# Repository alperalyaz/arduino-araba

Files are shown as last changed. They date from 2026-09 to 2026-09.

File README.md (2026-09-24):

# Faruk'un Arduino Arabası

Yıllar önce bir robotik kodlama setiyle yapılmış "çarpmayan araba" projesinin
yeniden canlandırılması. Orijinal kod kayıp (karttan geri alınamıyor), her şey sıfırdan yazılıyor.

## Donanım

| Parça | Model | Durum |
|---|---|---|
| Kart | Arduino Uno R3 klonu (EDUBOTICS), CH340 USB | ✅ Çalışıyor |
| Motor sürücü | L298N, **HW-095** | ✅ Hazır, jumper'ları ayarlandı |
| Mesafe sensörü | HC-SR04 (çok modlu klon, fabrika modu standart) | ✅ Çalışıyor, test edildi |
| Motorlar | 2× sarı TT redüktörlü, tekerlekli | ⏳ Test edilmedi |
| Çizgi sensörü | 2× HW-870 (TCRT5000), 4 pinli | ⏳ Bağlanmadı |
| Pil | 2× 18650, yeni, tam şarjlı | ✅ Hazır |
| Gövde | Lazer kesim ahşap, marka NCT, ön bilyeli teker | — |

**Port:** COM3 &nbsp;•&nbsp; **FQBN:** `arduino:avr:uno` &nbsp;•&nbsp; "old bootloader" gerekmiyor

## Dosyalar

| Dosya | Ne işe yarar |
|---|---|
| [KABLO-HARITASI.md](KABLO-HARITASI.md) | **Ana referans.** Hangi kablo nereye. |
| [KAYRA.md](KAYRA.md) | Uygulayacak kişi için adım adım talimat |
| `BlinkTest/` | Kart canlı mı — en temel test |
| `MesafeTest/` | HC-SR04 ölçüm testi (pil gerekmez) |
| `MotorTest/` | Motorları tek tek döndürür (pil gerekir) |
| `CizgiTest/` | HW-870 testi (henüz kullanılmadı) |
| `ardiuno-claude.cmd` | Masaüstü kısayolunun çalıştırdığı dosya |

## Komutlar

Derle ve yükle:

```bash
"C:\Program Files\Arduino CLI\arduino-cli.exe" compile --fqbn arduino:avr:uno --upload -p COM3 C:\ardiuno\MesafeTest
```

Kart bağlı mı:

```bash
"C:\Program Files\Arduino CLI\arduino-cli.exe" board list
```

**Seri port okuma:** `arduino-cli monitor` kullanma — interaktif, oturumu kilitler.
Bunun yerine PowerShell `System.IO.Ports.SerialPort` + `ReadExisting()` döngüsü kullan,
`finally` içinde mutlaka `Close()`/`Dispose()`.

## Bilinen tuzaklar

- **L298N'in ENA/ENB jumper kapakları** çıkarılmış olmalı. Takılıyken Arduino pini bağlanırsa pin yanar.
- **"5V" jumper'ı takılı kalmalı.** Çıkarılırsa motorlar hiç dönmez.
- **Arduino 5V pini ile L298N +5V klemensi asla birleştirilmez.** (Arduino VIN'e pil gerilimi vermek serbest.)
- **Servo kullanılırsa** Timer1'i alır, D9 ve D10'un hız ayarı ölür. ENA/ENB bu yüzden D11 ve D6'da.
- **D0 ve D1 kullanılmaz** — seri port oradan konuşuyor.
- **Blink testinde 1 saniyelik desen kullanma** — fabrika çıkışı deseniyle aynı, sahte başarı üretir.
- Arduino'da **1 adet 5V, 3 adet GND** deliği var. Üç sensör birden bağlanacaksa
  **breadboard veya sensör shield** gerekli.

## Sıradaki

1. Motor testi (kablolama + pil) — `MotorTest/`
2. Çarpmayan araba (mesafe + motor birlikte)
3. Çizgi takibi (shield/breadboard geldikten sonra)

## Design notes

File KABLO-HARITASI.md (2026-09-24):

# FARUK'UN ARABASI - KABLO HARITASI  (v2, duzeltilmis)
23 Eylul 2026

## !!! KABLO TAKMADAN ONCE YAPILACAKLAR !!!

1. [TAMAM - 23 Eylul 2026] ENA/ENB jumper kapaklari CIKARILDI.
   Kart modeli: HW-095 (standart kirmizi L298N).
   Kapaklarin altindan cikan 2'ser pimden:
     - +5V klemensiyle SUREKLILIK VEREN (oten) pim  = +5V   -> kablo TAKMA
     - SUREKLILIK VERMEYEN (otmeyen) pim            = ENA / ENB -> KABLO BURAYA
   Kullanicinin elindeki duruma gore: OTMEYEN = ALTTAKI pim.
   Kablo takarken bu olcum 10 saniyede TEKRARLANACAK (kart cevrilirse ust/alt degisir).
2. "5V" jumper'i (kartin orta-sol kisminda, 102 yazan parcanin yaninda)
   YERINDE KALACAK. Cikarilirsa motorlar hic donmez.
3. Sokmeden once FOTOGRAF cek ve her kabloyu BANTLA ETIKETLE.
4. Her takma/sokme isleminde: kirmizi anahtar KAPALI + USB CIKIK.

## ARDUINO PIN HARITASI

### Motor surucu (L298N) - 6 kablo, ARDISIK
| L298N ustundeki yazi | Arduino deligi | Ne ise yarar |
|---|---|---|
| ENA | 11 | Sol motor HIZ |
| IN1 | 10 | Sol motor YON |
| IN2 | 9 | Sol motor YON |
| IN3 | 8 | Sag motor YON |
| IN4 | 7 | Sag motor YON |
| ENB | 6 | Sag motor HIZ |

11-10-9-8-7-6 sirayla iniyor. Serit kablo duz gider.

NEDEN 10 ve 9 DEGIL de 11 ve 6?  Servo motor kullanilirsa Arduino'nun
ic sayaci 9 ve 10'un hiz ayarini KAPATIYOR. O zaman motorlar yavas
gitmek yerine TAM GAZ kalkar. 11 ve 6 bundan etkilenmiyor.

### Mesafe sensoru (HC-SR04) - 4 kablo
| Sensor ustundeki yazi | Arduino deligi |
|---|---|
| VCC | 5V |
| Trig | 4 |
| Echo | 2 |
| GND | GND |

### Cizgi sensorleri (HW-870) - EN SON ASAMA
| Sensor | VCC | GND | DO  |
|---|-----|-----|-----|
| Sol | 5V  | GND | A0  |
| Sag | 5V  | GND | A1  |

## GUC BAGLANTISI

### Test asamasinda (tekerlekler havada)
- Arduino: USB'den beslenir
- Pil (+) -> SIGORTA (2-3 A) -> L298N "+12V" klemensi
- Pil (-) -> L298N "GND" klemensi
- L298N "GND" -> Arduino "GND"      <-- ILK BAGLANAN, SON SOKULEN
- L298N "+5V" -> HICBIR SEY

### Araba yerde giderken (USB cikik)
- Pil (+) -> SIGORTA -> hem L298N "+12V" hem Arduino "VIN"
- Pil (-) -> L298N "GND" ve Arduino "GND"

## MUTLAK KURALLAR
- Arduino "5V" pini ile L298N "+5V" klemensi ASLA BIRLESTIRILMEZ.
  (Arduino "VIN" pinine pil gerilimi vermek ise SERBEST ve dogru.)
- Pil (+) hattinda SIGORTA olmadan pil takilmaz.
- Motor hizi kodda en fazla 200 (255 degil). Ilk testler 120-150.
- Kirmizi = arti, Siyah = eksi. Istisnasiz.

## MOTORLAR
- Sol motorun 2 kablosu  -> OUT1 / OUT2
- Sag motorun 2 kablosu  -> OUT3 / OUT4
- Kutup yonu onemsiz; ters donerse duzeltiriz

## PIN YETMEZLIGI - EK MALZEME GEREKLI
Arduino'da 1 tane 5V deligi, 3 tane GND deligi var.
Ihtiyac: 5V'a 3 cihaz, GND'ye 4 cihaz. SIGMIYOR.
=> Breadboard (deneme tahtasi) veya vidali dagitim klemensi gerekli.

## BOSTA KALAN PINLER
D3, D5, D12, D13(dahili LED), A2, A3, A4, A5
D0 ve D1 KULLANILMAZ - seri port oradan konusuyor
Servo gerekirse -> D3 veya D12

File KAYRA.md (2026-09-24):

# KAYRA — YAPILACAKLAR

## 0. Değişmez kurallar

- Kablo takarken/sökerken: **USB çıkık, pil bağlı değil.**
- Test sırasında araba **kitabın üstünde**, tekerlekler havada.
- Kırmızı = artı. Siyah = eksi.
- Duman, koku veya ısınma → pili çıkar, USB'yi çek.

## 1. Kabloları bağla

Önce ortak şase:

```
L298N "GND" klemensi  →  Arduino GND
```

Sonra altı komut kablosu:

| L298N | Arduino |
|---|---|
| ENA | 11 |
| IN1 | 10 |
| IN2 | 9  |
| IN3 | 8  |
| IN4 | 7  |
| ENB | 6  |

ENA ve ENB'de iki pim var. Multimetreyi süreklilik kademesine al.
Bir probu L298N "+5V" klemensine koy. Ötmeyen pime kabloyu tak.

Sonra motorlar:

```
Sol motor  →  OUT1 / OUT2
Sağ motor  →  OUT3 / OUT4
```

Mesafe sensörü zaten bağlı. Dokunma. (Trig→4, Echo→2, Vcc→5V, Gnd→GND)

## 2. Pili henüz bağlama

## 3. USB'yi tak, kodu yükle

```bash
"C:\Program Files\Arduino CLI\arduino-cli.exe" compile --fqbn arduino:avr:uno --upload -p COM3 C:\ardiuno\MotorTest
```

## 4. Ekranı oku

Motorlar dönmeyecek (pil yok). Ekranda şu akmalı:

```
-> SOL motor - ILERI
-> SOL motor - GERI
-> SAG motor - ILERI
-> SAG motor - GERI
-> IKISI BIRDEN - ILERI
```

Akmıyorsa dur. Kabloyu kontrol et.

## 5. Pili bağla

```
Pil (+)  →  L298N "+12V"
Pil (-)  →  L298N "GND"
```

L298N "+5V" klemensine hiçbir şey bağlama.

## 6. İzle

- Ekranda "SOL" yazarken sol teker dönüyor mu?
- "ILERI" yazarken ileri yönde mi dönüyor?
- Ters dönen varsa **kabloyu değiştirme**, not al. Kodda düzeltilecek.

## 7. Raporla

Şunları yaz:
- Hangi motor, hangi komutta, hangi yöne döndü
- Dönmeyen motor var mı
- Isınan parça var mı

## Sorun çıkarsa

| Belirti | Bak |
|---|---|
| Hiçbir motor dönmüyor | L298N "5V" jumper'ı takılı mı |
| Ekranda yazı yok | USB kablosu, COM3 |
| Tek motor dönmüyor | O motorun OUT klemens vidaları sıkı mı |
| Hız ayarı çalışmıyor, hep tam gaz | ENA/ENB kapakları çıkmış mı |

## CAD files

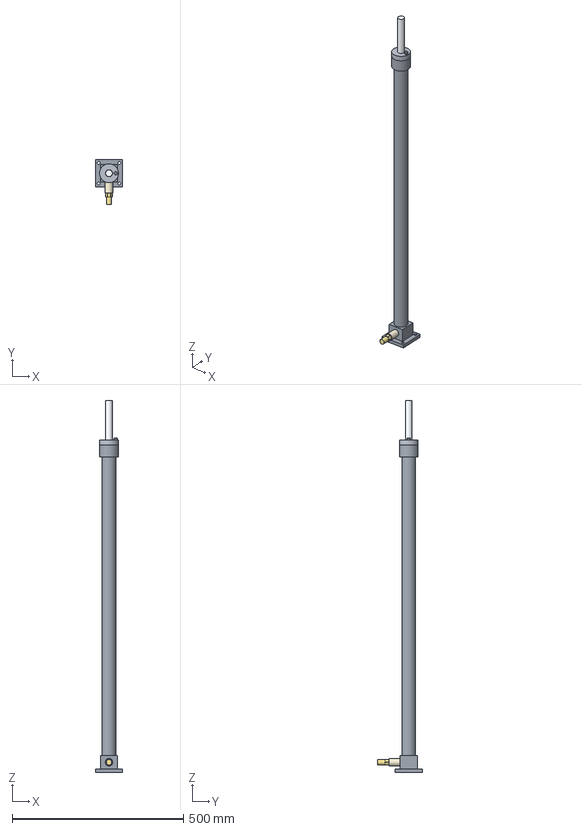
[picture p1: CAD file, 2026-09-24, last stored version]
maket-cad/hidrolik/silindir.step
80.0 x 131.0 x 1085.0 mm
SILINDIR_AYAK_PLAKASI
SILINDIR_DIP_BLOGU
SILINDIR_GOMLEK
SILINDIR_KAFA_GOVDESI
SILINDIR_KAFA_KAPAGI
SILINDIR_HAVA_ALMA_VIDASI
PISTON_MILI
STROK_SONU_HALKASI
HORTUM_PATLAMA_VALFI
HORTUM_RAKORU_SILINDIR

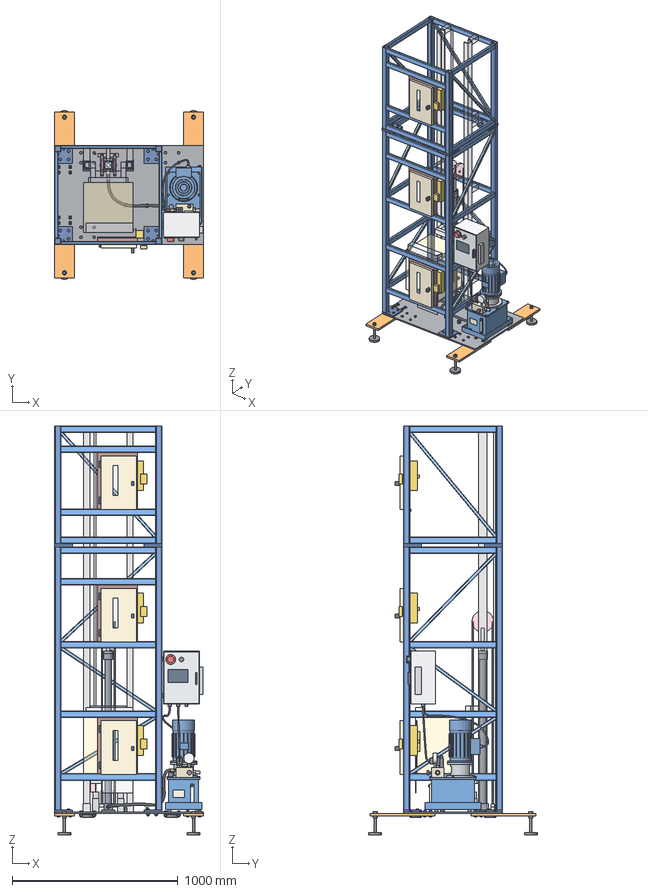
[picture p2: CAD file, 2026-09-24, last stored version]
maket-cad/taban-dikme/maket_taban_dikme.step
900.0 x 1019.4 x 2470.0 mm
TABAN_SACI
KOSE_PLAKASI_AYAK_SOL_ON
KOSE_PLAKASI_EK_ALT_SOL_ON
KOSE_PLAKASI_EK_UST_SOL_ON
DIKME_ALT_SOL_ON
DIKME_UST_SOL_ON
KOSE_PLAKASI_AYAK_SOL_ARKA
KOSE_PLAKASI_EK_ALT_SOL_ARKA
KOSE_PLAKASI_EK_UST_SOL_ARKA
DIKME_ALT_SOL_ARKA
DIKME_UST_SOL_ARKA
KOSE_PLAKASI_AYAK_SAG_ON
KOSE_PLAKASI_EK_ALT_SAG_ON
KOSE_PLAKASI_EK_UST_SAG_ON
DIKME_ALT_SAG_ON
DIKME_UST_SAG_ON
KOSE_PLAKASI_AYAK_SAG_ARKA
KOSE_PLAKASI_EK_ALT_SAG_ARKA
KOSE_PLAKASI_EK_UST_SAG_ARKA
DIKME_ALT_SAG_ARKA
DIKME_UST_SAG_ARKA
DESTEK_KULAGI_SOL_ON
DESTEK_KULAGI_SOL_ARKA
DESTEK_KULAGI_SAG_ON
DESTEK_KULAGI_SAG_ARKA
KUSAK_ALT_ON_R1
KUSAK_ALT_ON_R2
KUSAK_ALT_ON_R3
KUSAK_ALT_ON_R4
KUSAK_ALT_ON_R5
KUSAK_UST_ON_R6
KUSAK_UST_ON_R7
KUSAK_UST_ON_R8
KUSAK_UST_ON_R9
KUSAK_ALT_SOL_R1
KUSAK_ALT_SOL_R2
KUSAK_ALT_SOL_R3
KUSAK_ALT_SOL_R5
KUSAK_UST_SOL_R6
KUSAK_UST_SOL_R9
KUSAK_ALT_SAG_R1
KUSAK_ALT_SAG_R2
KUSAK_ALT_SAG_R3
KUSAK_ALT_SAG_R5
KUSAK_UST_SAG_R6
KUSAK_UST_SAG_R9
KUSAK_ALT_ARKA_R1
KUSAK_ALT_ARKA_R2
KUSAK_ALT_ARKA_R3
KUSAK_ALT_ARKA_R5
KUSAK_UST_ARKA_R6
KUSAK_UST_ARKA_R9
CAPRAZ_ALT_SOL_R1_R2
CAPRAZ_ALT_SOL_R2_R3
CAPRAZ_ALT_SOL_R3_R5
CAPRAZ_UST_SOL_R6_R9
CAPRAZ_ALT_SAG_R1_R2
CAPRAZ_ALT_SAG_R2_R3
CAPRAZ_ALT_SAG_R3_R5
CAPRAZ_UST_SAG_R6_R9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

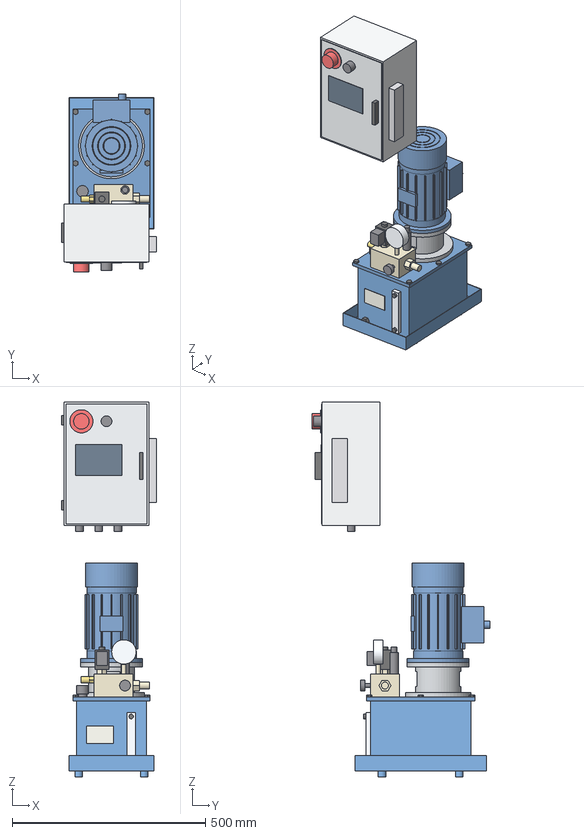
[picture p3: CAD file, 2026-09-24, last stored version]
maket-cad/hidrolik/unite.step
247.0 x 460.0 x 970.0 mm
YAG_TAVASI
TAVA_AYAGI_-85_-100
TAVA_AYAGI_-85_100
TAVA_AYAGI_85_-100
TAVA_AYAGI_85_100
TANK
TANK_KAPAGI
KAPAK_CIVATASI_-93_-133
KAPAK_CIVATASI_93_-133
KAPAK_CIVATASI_-93_133
KAPAK_CIVATASI_93_133
KAPAK_CIVATASI_-93_0
KAPAK_CIVATASI_93_0
CAN_KAMPANA
MOTOR_IEC71_B5_0_25kW
VALF_BLOGU
INIS_VALFI_KARTUSU
INIS_VALFI_BOBINI
INIS_VALFI_SOMUNU
INIS_VALFI_FISI_DIN
EMNIYET_VALFI
ELLE_INDIRME
MANOMETRE_BOGAZI
MANOMETRE
BASINC_SENSORU
HORTUM_RAKORU_BLOK
HAVA_DOLUM_TAPASI
SEVIYE_GOSTERGESI
SEVIYE_CIVATASI_46
SEVIYE_CIVATASI_156
BOSALTMA_TAPASI
UNITE_ETIKETI
KUMANDA_PANOSU
PANO_KAPAGI
ACIL_STOP
MOD_SECICI_KLASIK_KONFOR
EKRAN_HIZ_GRAFIGI
PANO_KOLU
PANO_KABLO_RAKORU_-83
PANO_KABLO_RAKORU_-33
PANO_KABLO_RAKORU_17
FREN_DIRENCI
PANO_ASKI_KULAGI_690
PANO_ASKI_KULAGI_910

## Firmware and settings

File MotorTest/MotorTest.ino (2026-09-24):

// MotorTest - motorlari TEK TEK, DUSUK HIZDA, kisa sure calistirir.
//
// !!! TEKERLEKLER HAVADA OLACAK !!!
// Arabayi bir kitabin ya da kutunun ustune koy, tekerlekler bosta donsun.
// Yere koyma - kacar.
//
// Mesafe sensoru bu kodda KULLANILMIYOR. Sadece motorlar.

// --- L298N baglantilari (KABLO-HARITASI.md ile ayni) ---
const int ENA = 11;   // sol motor hiz
const int IN1 = 10;   // sol motor yon
const int IN2 = 9;    // sol motor yon
const int IN3 = 8;    // sag motor yon
const int IN4 = 7;    // sag motor yon
const int ENB = 6;    // sag motor hiz

// --- Guvenlik sinirlari ---
const int HIZ      = 140;   // 0-255 arasi. 140 = yaklasik yarim gaz.
const int MAX_HIZ  = 200;   // Bunun ustune ASLA cikilmayacak.
const int SURE     = 1500;  // her hareket 1.5 saniye
const int MOLA     = 1000;  // hareketler arasi 1 saniye duraklama

void setup() {
  pinMode(ENA, OUTPUT); pinMode(IN1, OUTPUT); pinMode(IN2, OUTPUT);
  pinMode(ENB, OUTPUT); pinMode(IN3, OUTPUT); pinMode(IN4, OUTPUT);
  hepsiniDurdur();

  Serial.begin(9600);
  delay(300);
  Serial.println("=====================================");
  Serial.println("  MOTOR TESTI");
  Serial.println("  TEKERLEKLER HAVADA OLMALI!");
  Serial.println("=====================================");
  Serial.print("Hiz ayari: "); Serial.print(HIZ);
  Serial.print(" / 255  (guvenlik tavani: "); Serial.print(MAX_HIZ); Serial.println(")");
  Serial.println();
  Serial.println("5 saniye sonra basliyor...");
  for (int i = 5; i >= 1; i--) { Serial.print(i); Serial.println("..."); delay(1000); }
}

void loop() {
  adim("SOL motor - ILERI");
  solMotor(HIZ, true);   delay(SURE);  hepsiniDurdur(); delay(MOLA);

  adim("SOL motor - GERI");
  solMotor(HIZ, false);  delay(SURE);  hepsiniDurdur(); delay(MOLA);

  adim("SAG motor - ILERI");
  sagMotor(HIZ, true);   delay(SURE);  hepsiniDurdur(); delay(MOLA);

  adim("SAG motor - GERI");
  sagMotor(HIZ, false);  delay(SURE);  hepsiniDurdur(); delay(MOLA);

  adim("IKISI BIRDEN - ILERI");
  solMotor(HIZ, true); sagMotor(HIZ, true);
  delay(SURE);  hepsiniDurdur(); delay(MOLA);

  Serial.println();
  Serial.println(">>> Tur bitti. 5 saniye mola. <<<");
  Serial.println("Bir sey ters gittiyse USB'yi cek ya da anahtari kapat.");
  Serial.println();
  delay(5000);
}

// ---------- yardimci fonksiyonlar ----------

void adim(const char* mesaj) {
  Serial.print("-> ");
  Serial.println(mesaj);
}

int guvenliHiz(int h) {
  if (h > MAX_HIZ) return MAX_HIZ;   // tavani asamaz
  if (h < 0)       return 0;
  return h;
}

void solMotor(int hiz, bool ileri) {
  digitalWrite(IN1, ileri ? HIGH : LOW);
  digitalWrite(IN2, ileri ? LOW  : HIGH);
  analogWrite(ENA, guvenliHiz(hiz));
}

void sagMotor(int hiz, bool ileri) {
  digitalWrite(IN3, ileri ? HIGH : LOW);
  digitalWrite(IN4, ileri ? LOW  : HIGH);
  analogWrite(ENB, guvenliHiz(hiz));
}

void hepsiniDurdur() {
  analogWrite(ENA, 0);
  analogWrite(ENB, 0);
  digitalWrite(IN1, LOW); digitalWrite(IN2, LOW);
  digitalWrite(IN3, LOW); digitalWrite(IN4, LOW);
}

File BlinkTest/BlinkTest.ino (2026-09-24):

// BlinkTest - kartin calistigini dogrulayan test
// DESEN: 3 hizli cakma + 1.2 saniye mola. (Fabrika cikisi yavas
// yanip sonmeden kolayca ayirt edilsin diye boyle secildi.)

const int LED = LED_BUILTIN;   // kartin uzerindeki dahili isik
unsigned long tur = 0;         // kacinci tur

void setup() {
  pinMode(LED, OUTPUT);
  Serial.begin(9600);
  delay(300);
  Serial.println("=== BlinkTest basladi (3 cakma + mola) ===");
}

void loop() {
  tur++;
  Serial.print("Tur ");
  Serial.print(tur);
  Serial.println(" - 3 cakma");

  for (int i = 1; i <= 3; i++) {
    digitalWrite(LED, HIGH);
    delay(150);
    digitalWrite(LED, LOW);
    delay(150);
  }

  Serial.print("Tur ");
  Serial.print(tur);
  Serial.println(" - mola");
  delay(1200);
}

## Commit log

2026-09-24 Arduino araba projesi: ilk kayit
    Faruk'un eski robotik seti arabasinin canlandirilmasi.
    Calisan ve dogrulanan:
    - Arduino Uno R3 klonu (COM3, CH340), arduino-cli ile yukleme
    - HC-SR04 mesafe sensoru (Trig=D4, Echo=D2), olcum dogrulandi
    - L298N HW-095 motor surucu, ENA/ENB jumper kapaklari cikarildi
    Icerik:
    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
    [hidrolik_parca_listesi.csv, kesim_listesi.csv, maket_taban_dikme.step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]
2026-09-24 maket-cad klasorunu depodan cikar
    Asansor maketi CAD calismasi C:\asansor projesine tasindi.
    Dosyalar diskte duruyor, sadece bu depodan dusuruldu.
    [hidrolik_parca_listesi.csv, kesim_listesi.csv, maket_taban_dikme.step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]
